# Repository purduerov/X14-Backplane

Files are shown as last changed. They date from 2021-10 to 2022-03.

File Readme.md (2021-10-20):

# Readme for X14-Backplane

Whenever you make a new part, download the datasheet and save it here _**and**_ with the part in the parts library

Always pull other people's changes before beginning to work
`git pull`

Be sure to push your changes after  working on them. Run:
1. `git add .` to add any files in this directory or a subdirectory
or `git add -u` to add any modified files
2. (Optional) `git clean -nX` to see what ignored files can be removed
	`git clean -fX` removes ignored files (Eagle backups)
3. `git commit -m "helpful commit message"` with a description of the work that you did
4. `git push` to push your work to github

Other helpful commands
* `git status` says information about modified and staged files
* `git log` shows the recent commits of the repository
* `git log filename.extension` show the recent commits for just that file
* `git checkout first-couple-letter-of-commit-id` lets you go back to a previous version
* `git checkout master` brings you back to the latest commit
* `git tag` lists the tags
* `git tag -a orderX -m "the version of the board placed for the X'th order"` tag a specific commit
* `git push --tags` needed to push tags to remote
* `git show orderX` show the commit log for the given tag
* `git checkout orderX` go back and interact with the files at the tagged commit

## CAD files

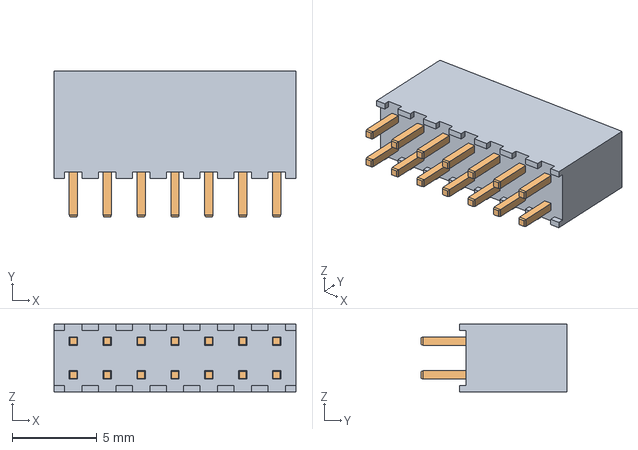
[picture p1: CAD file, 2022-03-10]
SQT-107-01-F-D/SQT-107-01-F-D.stp
14.3 x 8.64 x 4.00 mm
_S1SQT-107-01-F-D
_P1SQT-107-01-F-D

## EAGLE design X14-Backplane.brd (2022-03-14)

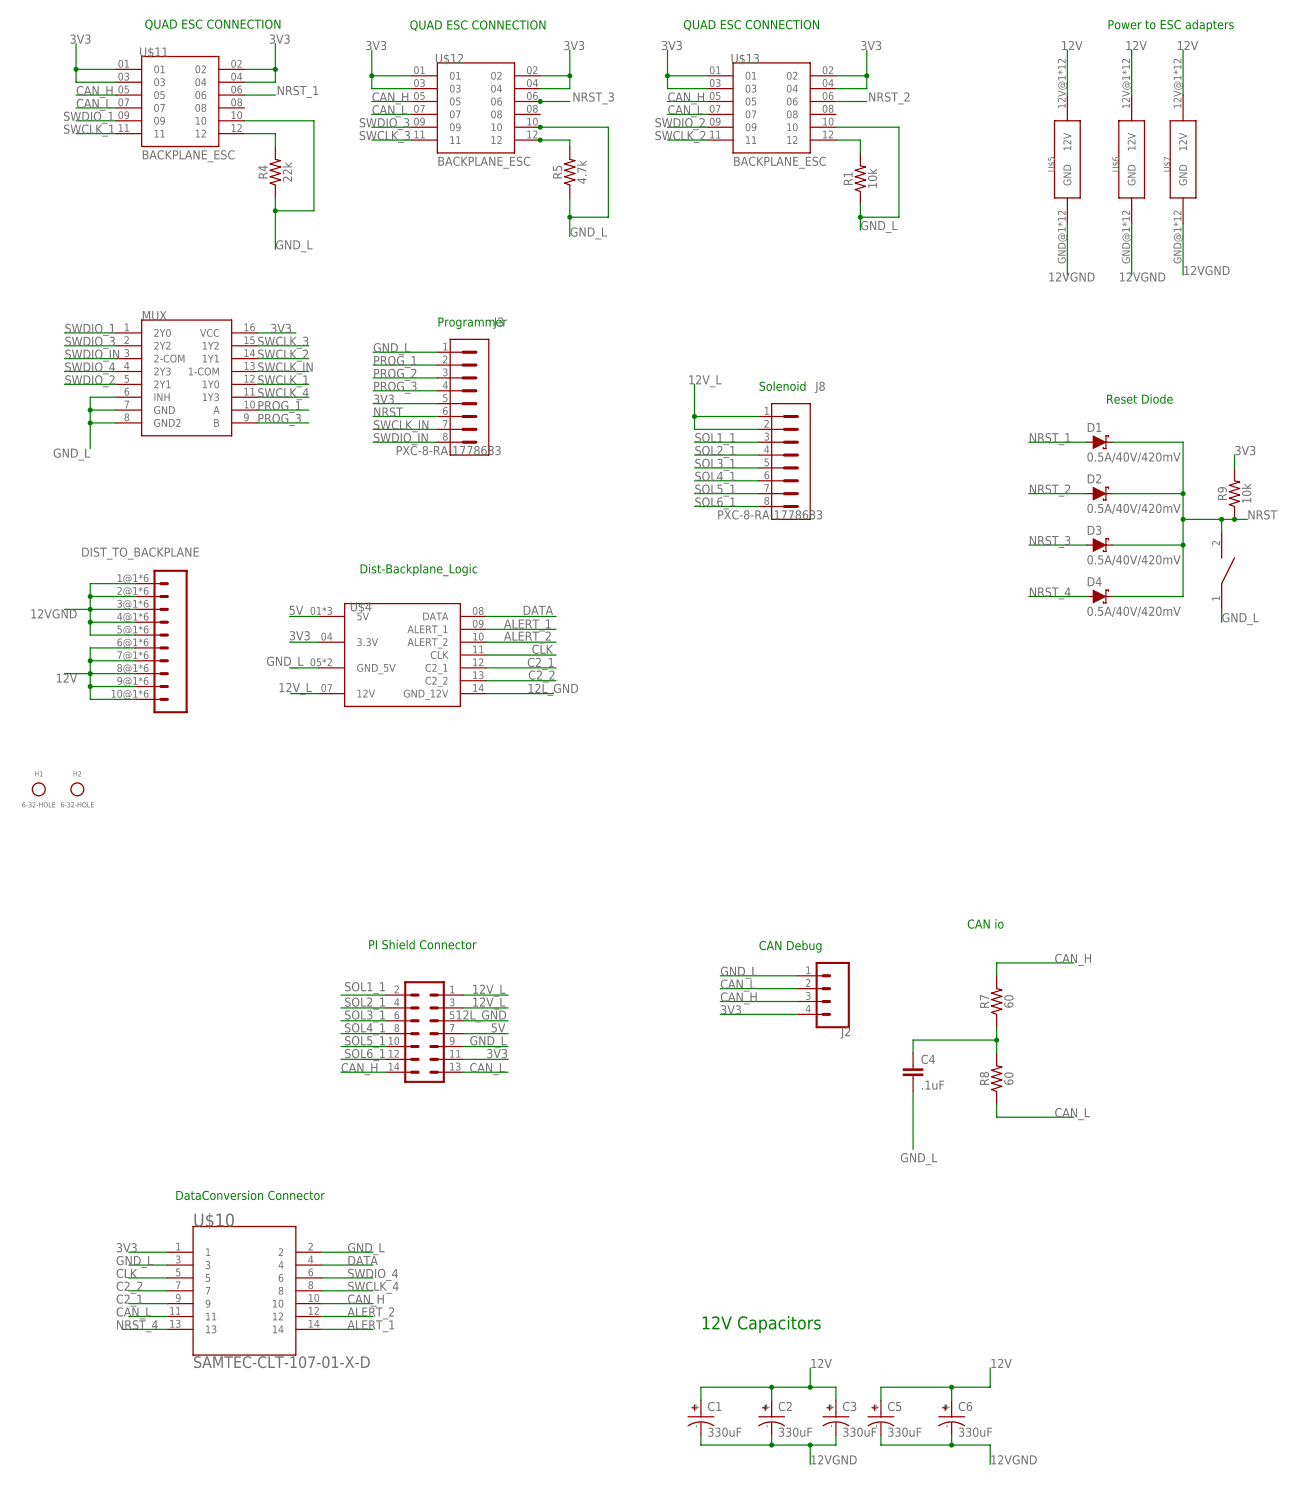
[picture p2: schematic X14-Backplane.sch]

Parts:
C1, C2, C3, C5, C6: 330uF; CAPAE1030X1050N
C4: .1uF; 0603
D1, D2, D3, D4: 0.5A/40V/420mV; SOD-323
DIST_TO_BACKPLANE: MPPT-10-01-01-L-RA-SD
H1, H2: 6-32-HOLE
J2: PXC-PTSM-04-RA-1778641
J3, J8: PXC-8-RA-1778683
MUX: TI-SN74LV4052A; SOIC-16
R1, R9: 10k; 0603
R4: 22k; 0603
R5: 4.7k; 0603
R7, R8: 60; 0603
U$4: BACKPLANE-DISTRIBUTION; SAMTEC_IPL1-107-01-X-D-K(B-D)
U$5, U$6, U$7: BACKPLANE_ESC_ADAPTER_PWRBKP; BACKPLANE_ESC_ADAPTER_BKP_PWR
U$8: DISCRETECOMPONENTS_SWITCH; DISCRETECOMPONENTS_SW_2512
U$9: 7X_CONN; IPL7X2
U$10: BACKPLANE->DATACONV; SAMTEC-CLT-107-01-X-D-BACKPLANE
U$11, U$12, U$13: BACKPLANE_ESC; SAMTEC_SQT-107-01-F-D

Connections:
3V3: J2.4, J3.5, MUX.16 (VCC), R9.2, U$4.04 (3.3V), U$9.11 (24), U$10.1, U$11.01, U$11.02, U$11.03, U$11.04, U$12.01, U$12.02, U$12.03, U$12.04, U$13.01, U$13.02, U$13.03, U$13.04
5V: U$4.01 (5V), U$4.02 (5V), U$4.03 (5V), U$9.7 (20)
12L_GND: U$4.14 (GND_12V), U$9.5 (18)
12V: C1.+, C2.+, C3.+, C5.+, C6.+, DIST_TO_BACKPLANE.6@1 (6), DIST_TO_BACKPLANE.6@2 (6), DIST_TO_BACKPLANE.6@3 (6), DIST_TO_BACKPLANE.6@4 (6), DIST_TO_BACKPLANE.6@5 (6), DIST_TO_BACKPLANE.6@6 (6), DIST_TO_BACKPLANE.7@1 (7), DIST_TO_BACKPLANE.7@2 (7), DIST_TO_BACKPLANE.7@3 (7), DIST_TO_BACKPLANE.7@4 (7), DIST_TO_BACKPLANE.7@5 (7), DIST_TO_BACKPLANE.7@6 (7), DIST_TO_BACKPLANE.8@1 (8), DIST_TO_BACKPLANE.8@2 (8), DIST_TO_BACKPLANE.8@3 (8), DIST_TO_BACKPLANE.8@4 (8), DIST_TO_BACKPLANE.8@5 (8), DIST_TO_BACKPLANE.8@6 (8), DIST_TO_BACKPLANE.9@1 (9), DIST_TO_BACKPLANE.9@2 (9), DIST_TO_BACKPLANE.9@3 (9), DIST_TO_BACKPLANE.9@4 (9), DIST_TO_BACKPLANE.9@5 (9), DIST_TO_BACKPLANE.9@6 (9), DIST_TO_BACKPLANE.10@1 (10), DIST_TO_BACKPLANE.10@2 (10), DIST_TO_BACKPLANE.10@3 (10), DIST_TO_BACKPLANE.10@4 (10), DIST_TO_BACKPLANE.10@5 (10), DIST_TO_BACKPLANE.10@6 (10), U$5.12V@1 (12V), U$5.12V@2 (12V), U$5.12V@3 (12V), U$5.12V@4 (12V), U$5.12V@5 (12V), U$5.12V@6 (12V), U$5.12V@7 (12V), U$5.12V@8 (12V), U$5.12V@9 (12V), U$5.12V@10 (12V), U$5.12V@11 (12V), U$5.12V@12 (12V), U$6.12V@1 (12V), U$6.12V@2 (12V), U$6.12V@3 (12V), U$6.12V@4 (12V), U$6.12V@5 (12V), U$6.12V@6 (12V), U$6.12V@7 (12V), U$6.12V@8 (12V), U$6.12V@9 (12V), U$6.12V@10 (12V), U$6.12V@11 (12V), U$6.12V@12 (12V), U$7.12V@1 (12V), U$7.12V@2 (12V), U$7.12V@3 (12V), U$7.12V@4 (12V), U$7.12V@5 (12V), U$7.12V@6 (12V), U$7.12V@7 (12V), U$7.12V@8 (12V), U$7.12V@9 (12V), U$7.12V@10 (12V), U$7.12V@11 (12V), U$7.12V@12 (12V)
12VGND: C1.-, C2.-, C3.-, C5.-, C6.-, DIST_TO_BACKPLANE.1@1 (1), DIST_TO_BACKPLANE.1@2 (1), DIST_TO_BACKPLANE.1@3 (1), DIST_TO_BACKPLANE.1@4 (1), DIST_TO_BACKPLANE.1@5 (1), DIST_TO_BACKPLANE.1@6 (1), DIST_TO_BACKPLANE.2@1 (2), DIST_TO_BACKPLANE.2@2 (2), DIST_TO_BACKPLANE.2@3 (2), DIST_TO_BACKPLANE.2@4 (2), DIST_TO_BACKPLANE.2@5 (2), DIST_TO_BACKPLANE.2@6 (2), DIST_TO_BACKPLANE.3@1 (3), DIST_TO_BACKPLANE.3@2 (3), DIST_TO_BACKPLANE.3@3 (3), DIST_TO_BACKPLANE.3@4 (3), DIST_TO_BACKPLANE.3@5 (3), DIST_TO_BACKPLANE.3@6 (3), DIST_TO_BACKPLANE.4@1 (4), DIST_TO_BACKPLANE.4@2 (4), DIST_TO_BACKPLANE.4@3 (4), DIST_TO_BACKPLANE.4@4 (4), DIST_TO_BACKPLANE.4@5 (4), DIST_TO_BACKPLANE.4@6 (4), DIST_TO_BACKPLANE.5@1 (5), DIST_TO_BACKPLANE.5@2 (5), DIST_TO_BACKPLANE.5@3 (5), DIST_TO_BACKPLANE.5@4 (5), DIST_TO_BACKPLANE.5@5 (5), DIST_TO_BACKPLANE.5@6 (5), U$5.GND@1 (GND), U$5.GND@2 (GND), U$5.GND@3 (GND), U$5.GND@4 (GND), U$5.GND@5 (GND), U$5.GND@6 (GND), U$5.GND@7 (GND), U$5.GND@8 (GND), U$5.GND@9 (GND), U$5.GND@10 (GND), U$5.GND@11 (GND), U$5.GND@12 (GND), U$6.GND@1 (GND), U$6.GND@2 (GND), U$6.GND@3 (GND), U$6.GND@4 (GND), U$6.GND@5 (GND), U$6.GND@6 (GND), U$6.GND@7 (GND), U$6.GND@8 (GND), U$6.GND@9 (GND), U$6.GND@10 (GND), U$6.GND@11 (GND), U$6.GND@12 (GND), U$7.GND@1 (GND), U$7.GND@2 (GND), U$7.GND@3 (GND), U$7.GND@4 (GND), U$7.GND@5 (GND), U$7.GND@6 (GND), U$7.GND@7 (GND), U$7.GND@8 (GND), U$7.GND@9 (GND), U$7.GND@10 (GND), U$7.GND@11 (GND), U$7.GND@12 (GND)
12V_L: J8.1, J8.2, U$4.07 (12V), U$9.1 (14), U$9.3 (16)
ALERT_1: U$4.09 (ALERT_1), U$10.14
ALERT_2: U$4.10 (ALERT_2), U$10.12
C2_1: U$4.12 (C2_1), U$10.9
C2_2: U$4.13 (C2_2), U$10.7
CAN_H: J2.3, R7.2, U$9.14 (2), U$10.10, U$11.05, U$12.05, U$13.05
CAN_L: J2.2, R8.1, U$9.13 (1), U$10.11, U$11.07, U$12.07, U$13.07
CLK: U$4.11 (CLK), U$10.5
DATA: U$4.08 (DATA), U$10.4
ESCID_1: R4.2, U$11.12
ESCID_2: R1.2, U$13.12
ESCID_3: R5.2, U$12.12
GND_L: C4.2, J2.1, J3.1, MUX.6 (INH), MUX.7 (GND), MUX.8 (GND2), R1.1, R4.1, R5.1, U$4.05 (GND_5V), U$4.06 (GND_5V), U$8.1, U$9.9 (22), U$10.2, U$10.3, U$11.10, U$12.10, U$13.10
unnamed: C4.1, R7.1, R8.2
NRST: D1.C, D2.C, D3.C, D4.C, J3.6, R9.1, U$8.2
NRST_1: D1.A, U$11.06
NRST_2: D2.A, U$13.06
NRST_3: D3.A, U$12.06
NRST_4: D4.A, U$10.13
PROG_1: J3.2, MUX.10 (A)
PROG_2: J3.3
PROG_3: J3.4, MUX.9 (B)
SOL1_1: J8.3, U$9.2 (13)
SOL2_1: J8.4, U$9.4 (15)
SOL3_1: J8.5, U$9.6 (17)
SOL4_1: J8.6, U$9.8 (19)
SOL5_1: J8.7, U$9.10 (21)
SOL6_1: J8.8, U$9.12 (23)
SWCLK_1: MUX.12 (1Y0), U$11.11
SWCLK_2: MUX.14 (1Y1), U$13.11
SWCLK_3: MUX.15 (1Y2), U$12.11
SWCLK_4: MUX.11 (1Y3), U$10.8
SWCLK_IN: J3.7, MUX.13 (1-COM)
SWDIO_1: MUX.1 (2Y0), U$11.09
SWDIO_2: MUX.5 (2Y1), U$13.09
SWDIO_3: MUX.2 (2Y2), U$12.09
SWDIO_4: MUX.4 (2Y3), U$10.6
SWDIO_IN: J3.8, MUX.3 (2-COM)

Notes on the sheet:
CAN Debug
Programmer
QUAD ESC CONNECTION
Dist-Backplane_Logic
Solenoid
Power to ESC adapters
Reset Diode
PI Shield Connector
CAN io
DataConversion Connector
12V Capacitors

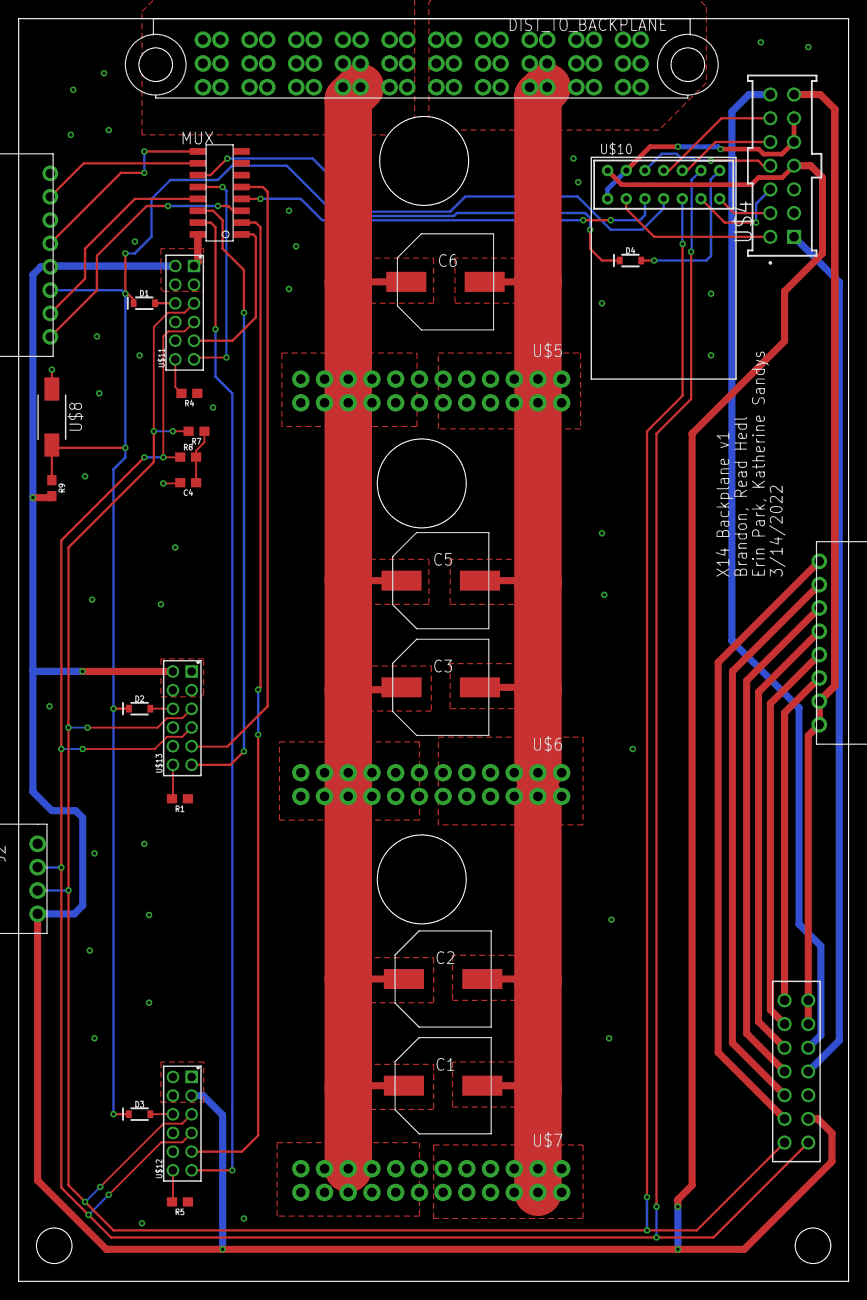
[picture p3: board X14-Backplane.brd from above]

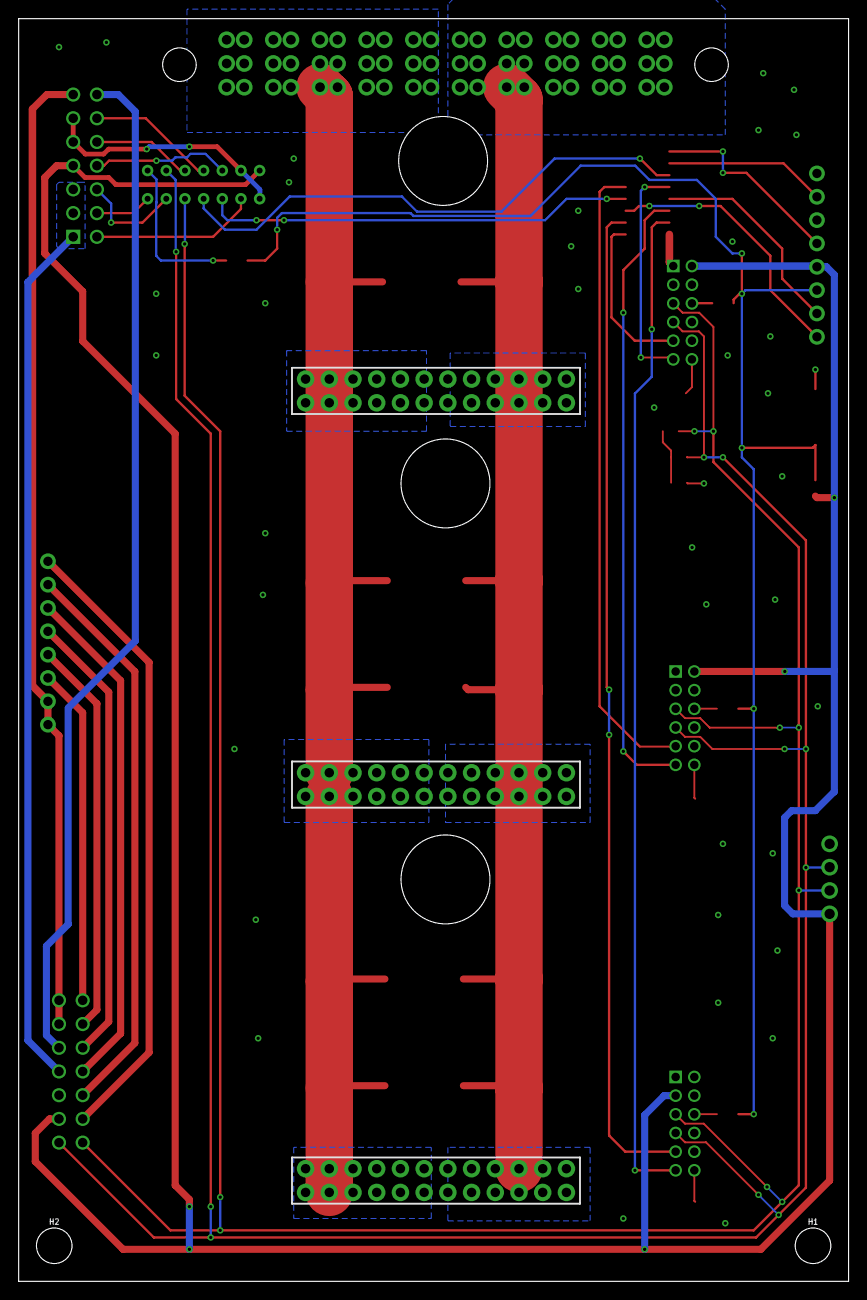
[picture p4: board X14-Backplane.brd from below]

Board: 2 copper layers, 88.9 x 135.3 mm, 33 parts (2 on the bottom side), 42 nets.

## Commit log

2021-10-20 Design Review X14-Backplane
    X14-Backplane for design review
    [X14-Backplane.brd, X14-Backplane.sch]
2021-11-29 X14-Backplane 11/29
    This is the most up to date backplane as of 11/29/2021
    [X14-Backplane.brd, X14-Backplane.sch]
2021-12-02 X14-Backplane 12/2
    Most up to date backplane as of 12/2/2021
    [X14-Backplane.brd, X14-Backplane.sch]
2021-12-02 Revert "sfdgfhg"
    This reverts commit 89fcb60d7aa2de489dc8c4b854d40a80c75a218c.
    [X14-Backplane.brd]
2021-12-03 X14-Backplane 12/2 #2
    This has more signals routed except from those from dist (top right of board) and the power between the ESC's
    [X14-Backplane.brd]
2021-12-04 X14-Backplane 12/4
    This is the most up to date version as of 12/4/2021
    [X14-Backplane.brd, X14-Backplane.sch]
2021-12-30 rerouted board
    [X14-Backplane.brd, X14-Backplane.sch]
2021-12-30 some adjustments
    [X14-Backplane.brd]
2021-12-31 Implemented conversion board
    [X14-Backplane.brd, X14-Backplane.sch]
2021-12-31 second round of edits to bkplane
    [X14-Backplane.brd, X14-Backplane.sch]
2021-12-31 added ESC adapter holes and some capacitors
    [X14-Backplane.brd, X14-Backplane.sch]
2022-01-02 TODO: Fix CAN line, Silkcreen
    [X14-Backplane.brd, X14-Backplane.sch]
2022-01-03 todo: new cap, silkscreen
    [X14-Backplane.brd]
2022-01-07 Added Silkscreen, last cap
    [X14-Backplane.brd]
2022-01-07 almost ordered without the tstop polygon
    [X14-Backplane.brd]
2022-03-10 new connector UwU SQT
    [SQT-107-01-F-D.stp, X14-Backplane.brd, X14-Backplane.sch]
2022-03-14 shrunk board to better fit in box for v2
    [X14-Backplane.brd, X14-Backplane.sch]

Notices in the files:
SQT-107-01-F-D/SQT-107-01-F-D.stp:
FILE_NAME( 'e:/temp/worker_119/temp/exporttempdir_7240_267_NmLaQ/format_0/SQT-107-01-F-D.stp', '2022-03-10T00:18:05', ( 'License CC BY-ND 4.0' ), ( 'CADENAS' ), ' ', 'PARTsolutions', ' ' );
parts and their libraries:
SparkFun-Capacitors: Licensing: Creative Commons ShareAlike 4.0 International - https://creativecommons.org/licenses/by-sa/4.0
